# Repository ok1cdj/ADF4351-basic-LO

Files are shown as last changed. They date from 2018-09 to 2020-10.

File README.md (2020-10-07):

# ADF4351-basic-LO
Very simple software for PLL ADF4351 and ATTiny13  can be compiled with arduino and microcore
https://github.com/MCUdude/MicroCore

v 0.2 Ondra OK1CDJ 5/2020 ondra@ok1cdj.com
 
ADF4351 eval board from eBay or Ali for aprox. 17 USD. 
 
Please check the ADF4351 datasheet or use ADF4351 software
to get proper PLL register values.

# ADF4351-Beacon
Simple CW beacon. SW is also for ATTiny13 now or can use ATTINY45/85 on same PCB.
Beacon send string in morse code like - OK1CDJ JO70VA and then continous tone for 5s.

# ADF4351-Key
Version with external keying on PB0 of ATTiny13. Can be used as simple CW transmitter.

## PIN layout of ATTINY13/45/85
MCU is powered  by 3.3V directly from PLL board.

 pin 5 - PB0 external keying - optional

 pin 3 - PB4  to ADF4531 clock (CLK) 
 
 pin 2 - PB3 to ADF4531 data (DATA) 
 
 pin 7 - PB2 to ADF4531 latch enable (LE) 

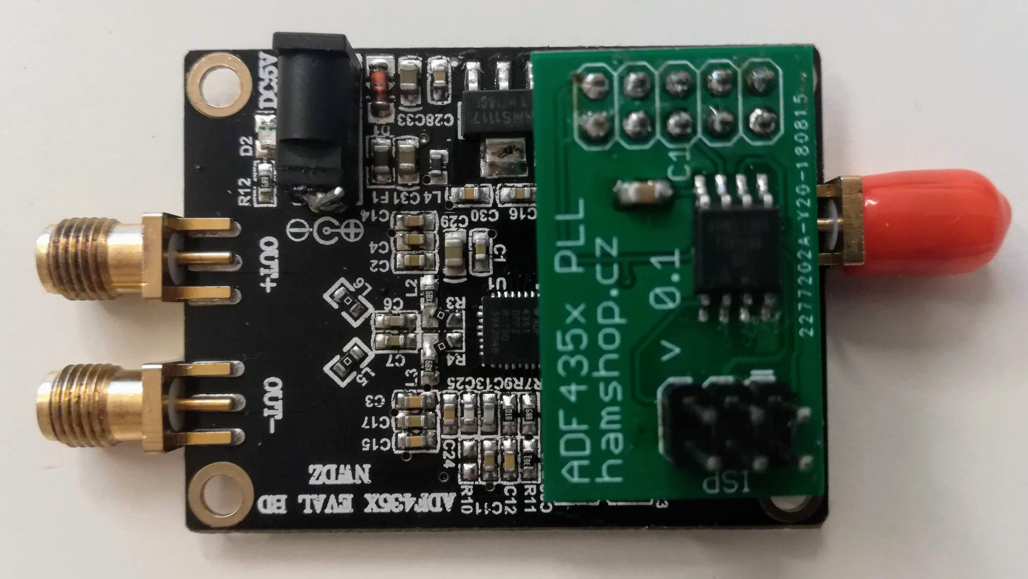
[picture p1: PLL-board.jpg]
board


Kit is available here:

https://www.hamshop.cz/pll-adf4351-c51/adf4351-ovladani-s-attiny13-stavebnice-i351/

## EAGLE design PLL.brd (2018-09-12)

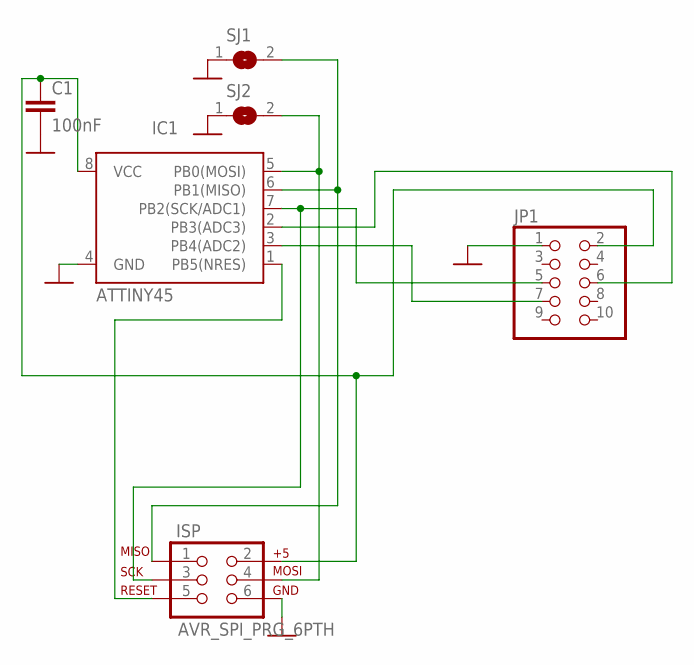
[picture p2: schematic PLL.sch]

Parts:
C1: 100nF; C0805
IC1: ATTINY45; SO08-EIAJ
ISP: AVR_SPI_PRG_6PTH; 2X3
JP1: PINHD-2X5; 2X05
SJ1, SJ2: SJ

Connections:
GND: C1.2, IC1.4 (GND), ISP.6, JP1.1, SJ1.1, SJ2.1
ISP: IC1.7 (PB2(SCK/ADC1)), ISP.3, JP1.5
unnamed: IC1.3 (PB4(ADC2)), JP1.7
unnamed: IC1.2 (PB3(ADC3)), JP1.6
unnamed: C1.1, IC1.8 (VCC), ISP.2, JP1.2
unnamed: IC1.6 (PB1(MISO)), ISP.1, SJ1.2
unnamed: IC1.5 (PB0(MOSI)), ISP.4, SJ2.2
unnamed: IC1.1 (PB5(NRES)), ISP.5

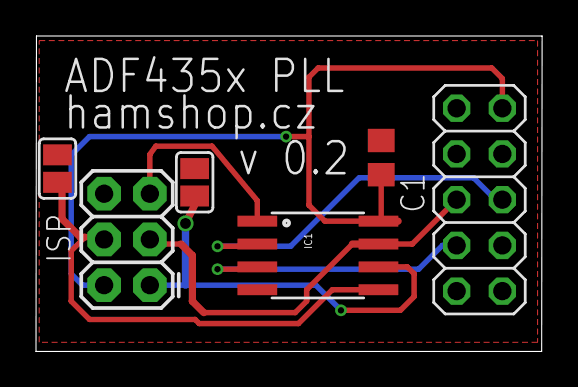
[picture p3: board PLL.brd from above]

Board: 2 copper layers, 28.1 x 17.5 mm, 6 parts (0 on the bottom side), 8 nets.

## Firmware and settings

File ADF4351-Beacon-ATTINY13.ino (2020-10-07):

/* CW beacon software for PLL ADF4351 and ATTiny13
 can be compiled with arduino 
 v 0.2 by Martin OK1VSR and  Ondra OK1CDJ 9/2018 ondra@ok1cdj.com
 
 
 Parts of this code is based on routines written by PA3FYM

 Morse Based on Simple Arduino Morse Beacon  
 Written by Mark VandeWettering K6HX
 
 Please check the ADF4351 datasheet or use ADF4351 software
 to get PLL register values.
 
 PIN layout
 PB4 ADF4531 clock (CLK)   
 PB3 ADF4531 data (DATA)
 PB2 ADF4531 latch enable (LE)
*/



const uint8_t morsetab[] PROGMEM = {
  '.', 106,     //1. znak
  ',', 115,     //2. znak
  '?', 76,      //3. znak
  '/', 41,      //4. znak
  'A', 6,       //5. znak
  'B', 17,      //6. znak
  'C', 21,      //7. znak
  'D', 9,       //8. znak
  'E', 2,       //9. znak
  'F', 20,      //10. znak
  'G', 11,      //11. znak
  'H', 16,      //12. znak
  'I', 4,       //13. znak
  'J', 30,      //14. znak
  'K', 13,      //15. znak
  'L', 18,      //16. znak
  'M', 7,       //17. znak
  'N', 5,       //18. znak
  'O', 15,      //19. znak
  'P', 22,      //20. znak
  'Q', 27,      //21. znak
  'R', 10,      //22. znak
  'S', 8,       //23. znak
  'T', 3,       //24. znak
  'U', 12,      //25. znak
  'V', 24,      //26. znak
  'W', 14,      //27. znak
  'X', 25,      //28. znak
  'Y', 29,      //29. znak
  'Z', 19,      //30. znak
  '1', 62,      //31. znak
  '2', 60,      //32. znak
  '3', 56,      //33. znak
  '4', 48,      //34. znak
  '5', 32,      //35. znak
  '6', 33,      //36. znak
  '7', 35,      //37. znak
  '8', 39,      //38. znak
  '9', 47,      //39. znak
  '0', 63       //40. znak
} ;

#define N_MORSE  80  //40 char * 2 byte  per char

// set speed of morse in WPM
     
#define speed 20
#define dotlen (1200/speed)
#define dashlen (3*(1200/speed))
     
char *str;


// Morse code tokens. 0 = dit, 1 = dah any other character will generate 8 dit error.

// NOTE: These need to be in ASCII code sequence to work
/*
char tokens [][7] = { "110011", "100001", // ,,-
                      "010101", "10010", // .,/
                      "11111", "01111", "00111", "00011", "00001", "00000", // 0,1,2,3,4,5
                      "10000", "11000", "11100", "11110", // 6,7,8,9
                      "111000", "10101", "<", // :,;,<"=",">","001100", // =,>,?
                      "@", // @,
                      "01", "1000", "1010", // A,B,C
                      "100", "0", "0010", // D,E,F
                      "110", "0000", "00", // G,H,I
                      "0111", "101", "0100", // J,K,L
                      "11", "10", "111", // M,N,O
                      "0110", "1101", "010", // P,Q,R
                      "000", "1", "001", // S,T,U
                      "0001", "011", "1001", // V,W,X
                      "1011", "1100"
                    }; // Y,Z }
;
*/
// PLL registers
long int r0, r1, r2, r3, r4, r5;
 

////////////////////////////////////////////////////////
void write2PLL(uint32_t PLLword) {         // clocks 32 bits word  directly to the ADF4351
                                           // msb (b31) first, lsb (b0) last 
  for (byte i=32; i>0; i--) {     // PLL word 32 bits 
    (PLLword & 0x80000000? PORTB |= 0b00001000 : PORTB &= 0b11110111);   // data on PB3                                                                           
    PORTB |= 0b00010000;                   // clock in bit on rising edge of CLK (PB4 = 1)
    PORTB &= 0b11101111;                   // CLK (PB4 = 0)      
    PLLword <<= 1;                         // rotate left for next bit
    } 
    PORTB |= 0b00000100;                   // latch in PLL word on rising edge of LE (PB2 = 1)
    PORTB &= 0b11111011;  // LE (PB2 = 0)      
    delayMicroseconds(1);
} 


// Routine to output a dit
void dit()
{
  write2PLL(r4);
  delay(dotlen);
  write2PLL(r4 & 0xffffffdf);
  delay(dotlen);
}

// Routine to output a dah
void dash()
{
  write2PLL(r4);
  delay(dashlen);
  write2PLL(r4 & 0xffffffdf);
  delay(dotlen);
}


// Look up a character in the tokens array and send it
void
send(char c)
{
  int i ;
  if (c == ' ') {

    delay(7 * dotlen) ;
    return ;
  }
  for (i = 0; i < N_MORSE; i+=2) {
    if (pgm_read_byte_near(morsetab+i) == c) {
      unsigned char p = pgm_read_byte_near(morsetab+i+1) ;

      while (p != 1) {
        if (p & 1)
          dash() ;
        else
          dit() ;
        p = p / 2 ;
      }
      delay(2 * dotlen) ;
      return ;
    }
  }
 //if we drop off the end, then we send a space

}

void
sendmsg(char *str)
{
  while (*str)
    send(*str++) ;

}


void setup () {   

DDRB  = 0xff; // PB are all outputs 
PORTB = 0x00; // make PB low

// Fout= 432.910 MHz +5dBm  only RF port
 r0 = 0x450A60;  
 r1 = 0x8009389;
 r2 = 0x4E42; 
 r3 = 0x4B3;
 r4 = 0xBC80FC;
 r5 = 0x580005; 

 // write from r5 to r0
     write2PLL(r5); 
     write2PLL(r4); 
     write2PLL(r3);
     write2PLL(r2);
     write2PLL(r1);
     write2PLL(r0);  

//     str = "OK1CDJ/B JO70VA";
     str = "OK1VSR/B JO69UR";
     write2PLL(r4 & 0xffffffdf);        // TX off 
     
}

// main loop 
void loop() {                                 
      delay(800);                         
      sendmsg(str);
      delay(350);                         // pause after beacon text
      write2PLL(r4);                     // then TX on 
      delay(5000);                       // 5 seconds TX
      write2PLL(r4 & 0xffffffdf);        // TX off   

}

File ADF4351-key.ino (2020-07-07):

/* Very simple software for PLL ADF4351 and ATTiny13
  can be compiled with arduino and microcore
  https://github.com/MCUdude/MicroCore
  v 0.1 Ondra OK1CDJ 5/2020 ondra@ok1cdj.com
  
  Parts of this code is based on routines written by PA3FYM

  Please check the ADF4351 datasheet or use ADF4351 software
  to get PLL register values.

  PIN layout
  PB0 key input - keyed low
  PB4 ADF4531 clock (CLK)
  PB3 ADF4531 data (DATA)
  PB2 ADF4531 latch enable (LE)
*/





// PLL registers
long int r0, r1, r2, r3, r4, r5;
#define KEY 0
int val = 0;

////////////////////////////////////////////////////////
void write2PLL(uint32_t PLLword) {         // clocks 32 bits word  directly to the ADF4351
  // msb (b31) first, lsb (b0) last
  for (byte i = 32; i > 0; i--) { // PLL word 32 bits
    (PLLword & 0x80000000 ? PORTB |= 0b00001001 : PORTB &= 0b11110111);  // data on PB3
    PORTB |= 0b00010001;                   // clock in bit on rising edge of CLK (PB4 = 1)
    PORTB &= 0b11101111;                   // CLK (PB4 = 0)
    PLLword <<= 1;                         // rotate left for next bit
  }
  PORTB |= 0b00000101;                   // latch in PLL word on rising edge of LE (PB2 = 1)
  PORTB &= 0b11111011;  // LE (PB2 = 0)
  delayMicroseconds(1);
}

void setup () {

  DDRB  = 0xfe; // PB are all outputs PB0 input
  PORTB = 0x01; // make PB low and PB0 high

  // Fout= 2450.050 only from main port

  r0 = 0x300008;
  r1 = 0x8008FA1;


  r2 = 0x4E42;
  r3 = 0x4B3;
  r4 = 0x8C803C;
  r5 = 0x580005;



  // write from r5 to r0
  write2PLL(r5);
  write2PLL(r4);
  write2PLL(r3);
  write2PLL(r2);
  write2PLL(r1);
  write2PLL(r0);

}

// main loop
void loop() {
  val = digitalRead(KEY);
  // TX ON/OFF can be used for CW keying
  if (val == 1)
    write2PLL(r4 & 0xffffffdf); //txoff
  else
    write2PLL(r4); //txon


}

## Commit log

2018-09-12 Schematic and PCB in EAGLE CAD
    [PLL.brd, PLL.sch]
2018-09-12 Complete board
